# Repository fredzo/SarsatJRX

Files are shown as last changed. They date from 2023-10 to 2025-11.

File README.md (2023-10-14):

# Sarsat JRX
Cospas/Sarsat 406MHz beacon decoder based on an ESP32 module.
This project was inspired by the work of F4GMU and F1LVT.

Field use during a SATER exerciser with Ardrasec 31 :

Field use

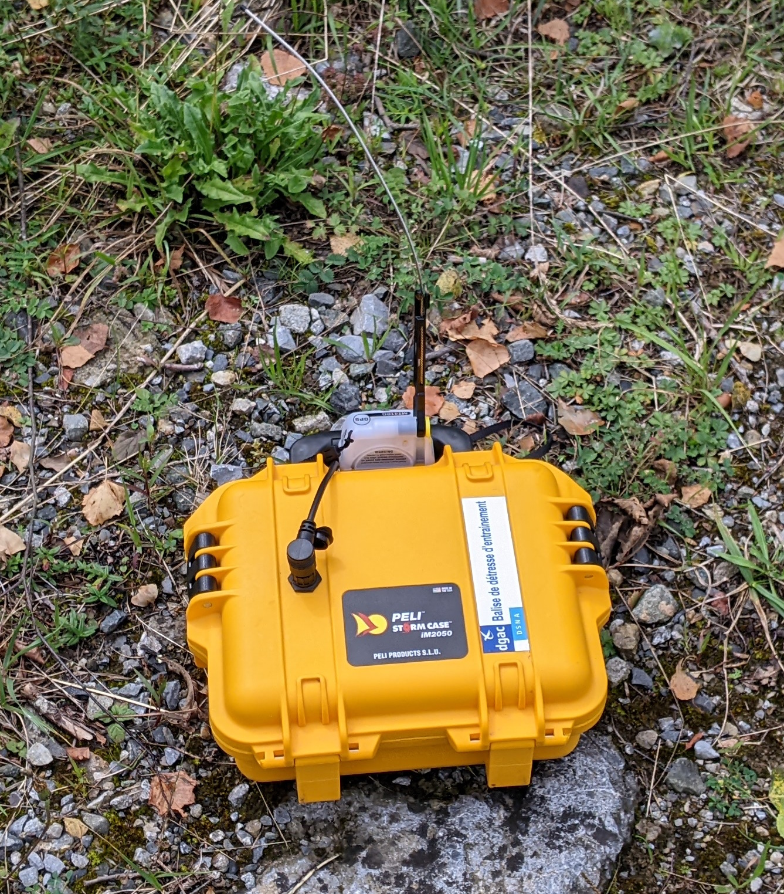
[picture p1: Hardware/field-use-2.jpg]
Field use


# Hardware
Input stage is based on F1LVT's "deriv-audio" board : http://www.f1lvt.com/files/346-DerivAudio-P3.90.pdf

Second stage is F1LVT's signal shaping stage from DECTRA decoder : http://www.f1lvt.com/files/333E-ConstructionDECTRA2274-P1-English.67.pdf

Audio signal can be provided by either the audio ouput of a receiver (in my case a FT3D portable) or from a NiceRF SA818-S UHF module.

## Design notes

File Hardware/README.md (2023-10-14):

# Hardware

The board used is an LilyGo LilyPi : https://opencircuit.fr/produit/lilygo-lily-pi-esp32-wifi-bluetooth-3.5-inch
Based on an ESP32-Wrover-E module from Espressif.

Input stage is based on F1LVT's "deriv-audio" board : http://www.f1lvt.com/files/346-DerivAudio-P3.90.pdf
Second stage is F1LVT's signal shaping stage from DECTRA decoder : http://www.f1lvt.com/files/333E-ConstructionDECTRA2274-P1-English.67.pdf

Audio signal can be provided by either the audio ouput of a receiver or from a NiceRF SA818-S UHF module.

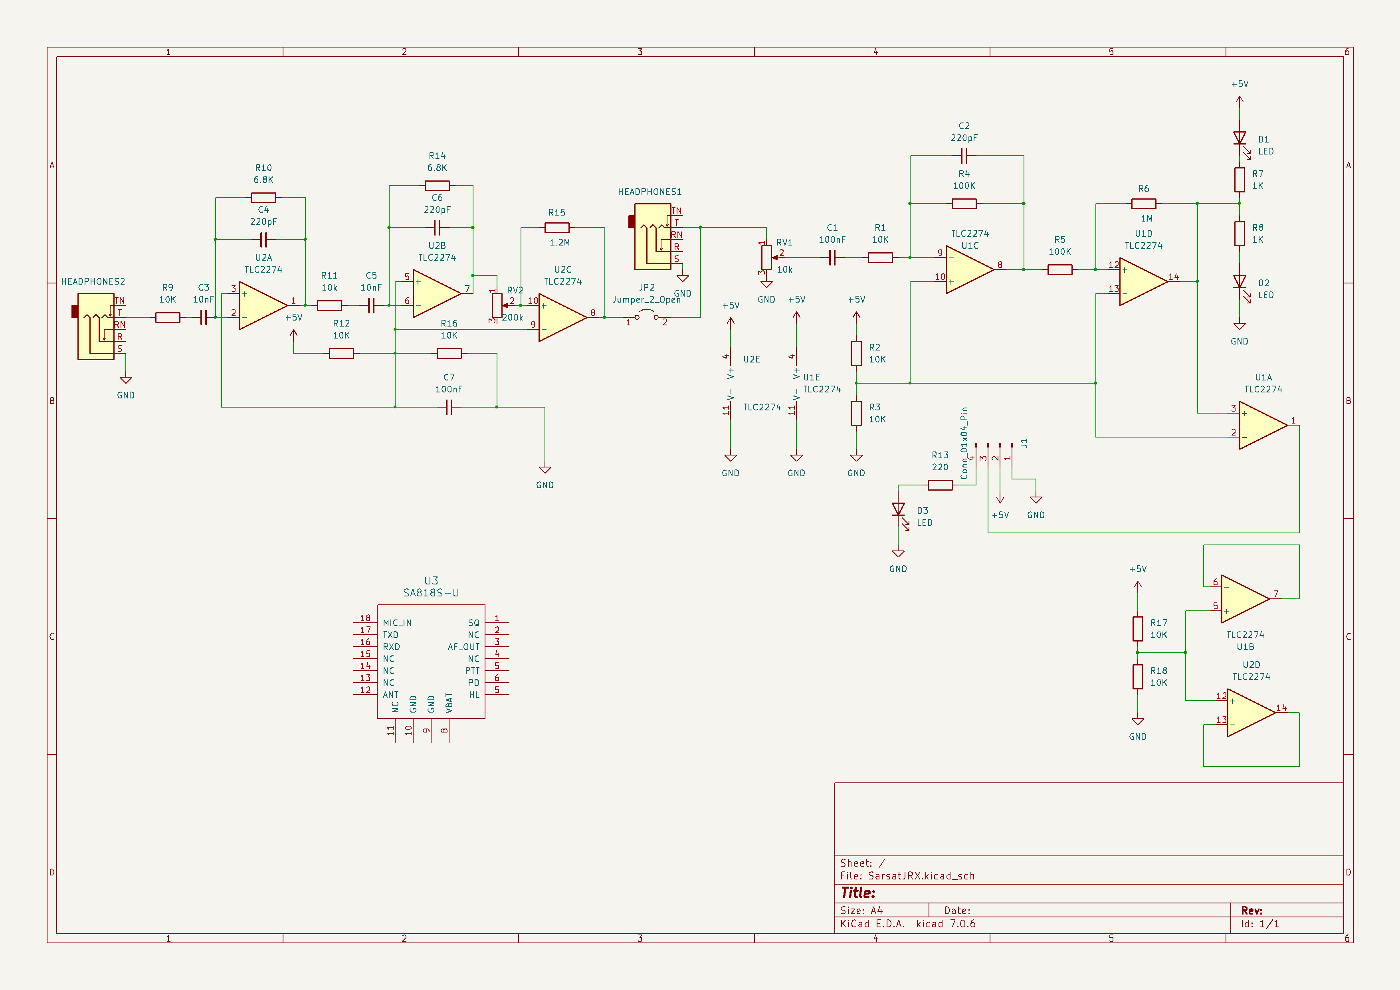
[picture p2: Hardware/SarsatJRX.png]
Schematic


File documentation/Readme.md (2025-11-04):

# **_SarsatJRX_** Beacon Decoder documentation
This is the documentation of F4JRX's SarsatJRX Beacon Decoder.

## Description
SarsatJRX is a COSBAS/SARSAT 406 MHz Beacon Decoder.

It's been developed by F4JRX, emergency radio operator from french civil security association [ADRASEC 31](https://adrasec31.canalblog.com/).
SarsatJRX is meant to be used on the ground to help locating emergency beacons from [COSPAS/SARSAT](https://www.cospas-sarsat.int/) system.

Once connected to an UHF FM receiver tuned to the beacon frequency, SarsatJRX will decode the 406 frames transmitted by the beacon and show its GPS coordinates.
Coordinates can sent to a phone for direction finding, either by scanning a QR Code on SarsatJRX's screen, or by connecting the [[dedicated app|SarsatJRX App]] to the decoder.

## Getting Started
### Hardware Setup
Check the [[Hardware Setup]] page for instructions on how to connect your SarsatJRX decoder to your receiver.
This page also describes different parts of you decoder.

### Configuration
The [Configuration] page will guide you through the basic configuration of the decoder.

### Main screen
The [Main Screen] page describes the information available on SarsatJRX's main screen.

### Connecting SarsatJRXApp
Once your SarsatJRX decoder is up and running, you may want ton connect it to SarsatJRXApp for easier communication with your phone.
Check the [[SarsatJRXApp]] connection page for instructions on how to connect the app to the decoder.

## Settings
There are various parameters that can be adjusted in SarsatJRX decoder.
Check the [[Settings]] page for more details.

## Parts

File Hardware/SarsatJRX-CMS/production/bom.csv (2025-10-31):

Designator | Footprint | Quantity | Value | LCSC Part #
BZ1 | MagneticBuzzer_PUI_AT-0927-TT-6-R-side-horn | 1 | Buzzer
C1, C10, C7, C8, C9 | 0603 | 5 | 100nF
C11, C13 | CP_EIA-3216-18_Kemet-A | 2 | 10uF
C12 | CP_Radial_D10.0mm_P5.00mm | 1 | 3300uF
C2, C4, C6 | 0603 | 3 | 220pF
C3, C5 | 0603 | 2 | 10nF
D1, D2, D3, D4 | LED_D5.0mm | 4 | LED
HEADPHONES1, HEADPHONES2 | PJ-307 | 2 | AudioJack3_SwitchTR
J3 | RPI_Hat_B+ | 1 | LilyPi GPIO Header
Q1 | SOT-23-3_L3.0-W1.7-P0.95-LS2.9-BR | 1 | S8050
R1, R11, R12, R16, R17, R18, R2, R24, R3, R9 | 0603 | 10 | 10K
R10, R14 | 0603 | 2 | 6.8K
R13, R19 | 0603 | 2 | 220
R15 | 0603 | 1 | 1.2M
R20, R21, R4, R5 | 0603 | 4 | 100K
R22, R7, R8 | 0603 | 3 | 1k
R23 | 0603 | 1 | 2k
R25 | 0603 | 1 | 51
R26 | 0603 | 1 | 0
R6 | 0603 | 1 | 1M
RV1 | Potentiometer_Bourns_3296W_Vertical | 1 | 10k
RV2 | Potentiometer_Bourns_3296W_Vertical | 1 | 200k
TP1, TP2, TP3, TP4, TP5, TP6, TP7, TP8 | TestPoint_Pad_D1.0mm | 8 | ~
U1, U2 | SOIC-14_3.9x8.7mm_P1.27mm | 2 | TLC2274

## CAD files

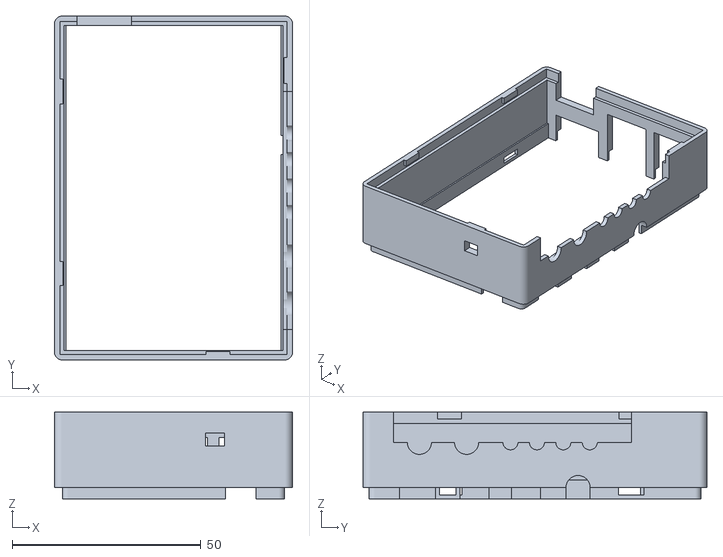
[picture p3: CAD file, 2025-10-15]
Hardware/Case/Extender.stl
63.0 x 91.0 x 23.0

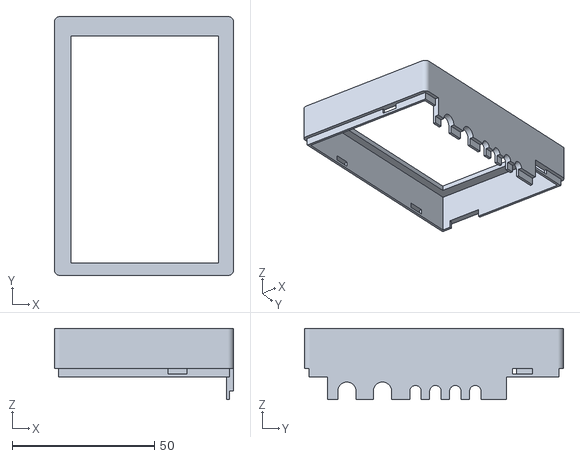
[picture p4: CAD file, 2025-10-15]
Hardware/Case/Top.stl
63.0 x 91.0 x 25.1

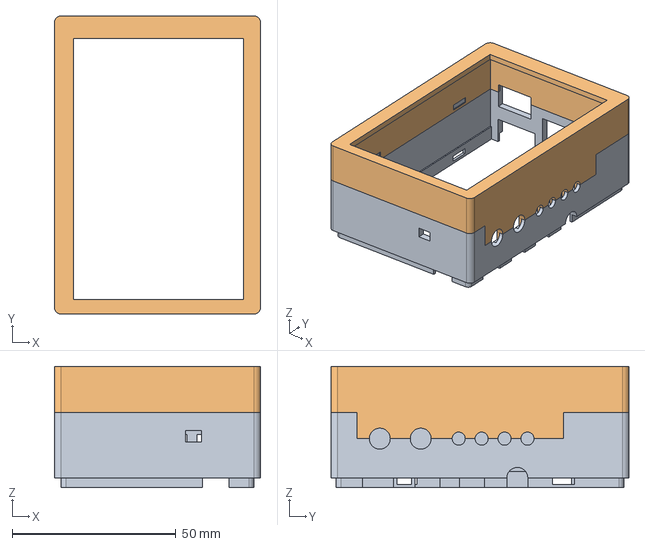
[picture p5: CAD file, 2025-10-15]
Hardware/Case/SarsatJRX Case Extender.FCStd
63.0 x 91.0 x 37.1 mm
Extender
Top

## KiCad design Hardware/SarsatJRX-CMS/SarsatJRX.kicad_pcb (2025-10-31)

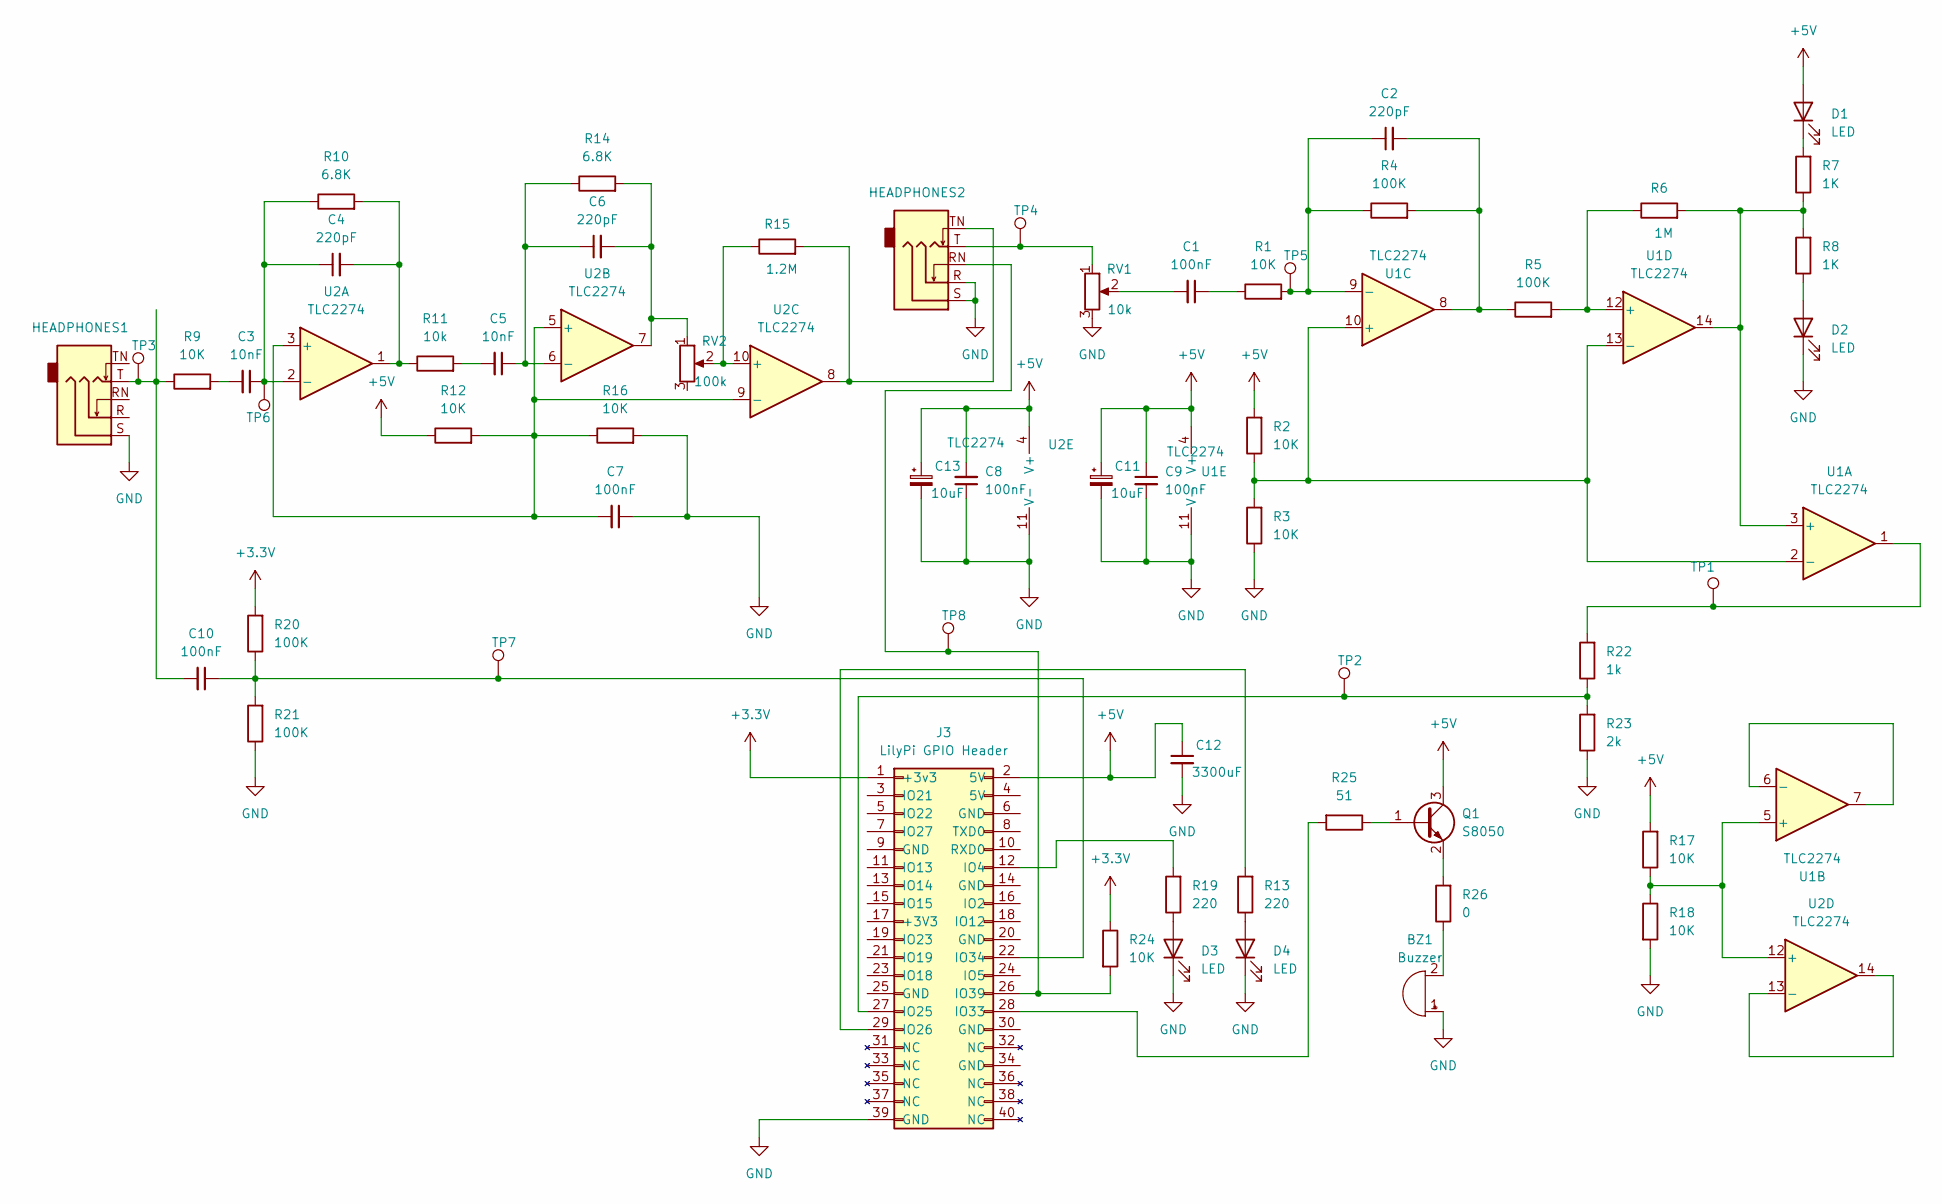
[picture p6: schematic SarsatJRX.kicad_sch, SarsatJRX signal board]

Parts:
BZ1: Buzzer; MagneticBuzzer_PUI_AT-0927-TT-6-R-side-horn
C1, C7, C8, C9, C10: 100nF; C_0603_1608Metric
C2, C4, C6: 220pF; C_0603_1608Metric
C3, C5: 10nF; C_0603_1608Metric
C11, C13: 10uF; CP_EIA-3216-18_Kemet-A
C12: 3300uF; CP_Radial_D8.0mm_P3.50mm
D1, D2, D3, D4: LED; LED_D5.0mm
HEADPHONES1, HEADPHONES2: AudioJack3_SwitchTR; PJ-307
J3: LilyPi GPIO Header; RPI_Hat_B+
Q1: S8050; SOT-23-3_L3.0-W1.7-P0.95-LS2.9-BR
R1, R2, R3, R9, R12, R16, R17, R18, R24: 10K; R_0603_1608Metric
R4, R5, R20, R21: 100K; R_0603_1608Metric
R6: 1M; R_0603_1608Metric
R7, R8: 1K; R_0603_1608Metric
R10, R14: 6.8K; R_0603_1608Metric
R11: 10k; R_0603_1608Metric
R13, R19: 220; R_0603_1608Metric
R15: 1.2M; R_0603_1608Metric
R22: 1k; R_0603_1608Metric
R23: 2k; R_0603_1608Metric
R25: 51; R_0603_1608Metric
R26: 0; R_0603_1608Metric
RV1: 10k; Potentiometer_Bourns_3296W_Vertical
RV2: 100k; Potentiometer_Bourns_3296W_Vertical
TP1, TP2, TP3, TP4, TP5, TP6, TP7, TP8: TestPoint_Pad_D1.0mm
U1, U2: TLC2274; SOIC-14_3.9x8.7mm_P1.27mm

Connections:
+3.3V: J3.1 (+3v3), R20.2, R24.1
+5V: C8.2, C9.1, C11.1, C12.1, C13.1, D1.2 (A), J3.2 (5V), Q1.3 (C), R2.2, R12.1, R17.2, U1.4 (V+), U2.4 (V+)
GND: BZ1.1 (+), C7.1, C8.1, C9.2, C11.2, C12.2, C13.2, D2.1 (K), D3.1 (K), D4.1 (K), HEADPHONES1.S, HEADPHONES2.R, HEADPHONES2.S, J3.39 (GND), R3.1, R16.2, R18.2, R21.1, R23.1, RV1.3, U1.11 (V-), U2.11 (V-)
unnamed: BZ1.2 (-), R26.1
unnamed: C1.1, R1.1
unnamed: C1.2, RV1.2
unnamed: C2.2, R4.2, R5.1, U1.8
unnamed: C3.2, R9.2
unnamed: C4.2, R10.2, R11.1, U2.1
unnamed: C5.2, R11.2
unnamed: C6.2, R14.2, RV2.1, U2.7
unnamed: C10.2, HEADPHONES1.T, R9.1, TP3.1
unnamed: D1.1 (K), R7.2
unnamed: D2.2 (A), R8.1
unnamed: D3.2 (A), R19.1
unnamed: D4.2 (A), R13.1
unnamed: HEADPHONES2.T, RV1.1, TP4.1
unnamed: HEADPHONES2.TN, R15.2, U2.8
unnamed: J3.12 (IO4), R19.2
unnamed: J3.27 (IO25), R22.1, R23.2, TP2.1
unnamed: J3.29 (IO26), R13.2
unnamed: J3.28 (IO33), R25.2
unnamed: C10.1, J3.22 (IO34), R20.1, R21.2, TP7.1
unnamed: HEADPHONES2.RN, J3.26 (IO39), R24.2, TP8.1
unnamed: Q1.1 (B), R25.1
unnamed: Q1.2 (E), R26.2
unnamed: R22.2, TP1.1, U1.1
unnamed: R6.2, R7.1, R8.2, U1.3 (+), U1.14
unnamed: R2.1, R3.2, U1.2 (-), U1.10 (+), U1.13 (-)
unnamed: R17.1, R18.1, U1.5 (+), U2.12 (+)
unnamed: U1.6 (-), U1.7
unnamed: C2.1, R1.2, R4.1, TP5.1, U1.9 (-)
unnamed: R5.2, R6.1, U1.12 (+)
unnamed: C7.2, R12.2, R16.1, U2.3 (+), U2.5 (+), U2.9 (-)
unnamed: C3.1, C4.1, R10.1, TP6.1, U2.2 (-)
unnamed: C5.1, C6.1, R14.1, U2.6 (-)
unnamed: R15.1, RV2.2, U2.10 (+)
unnamed: U2.13 (-), U2.14

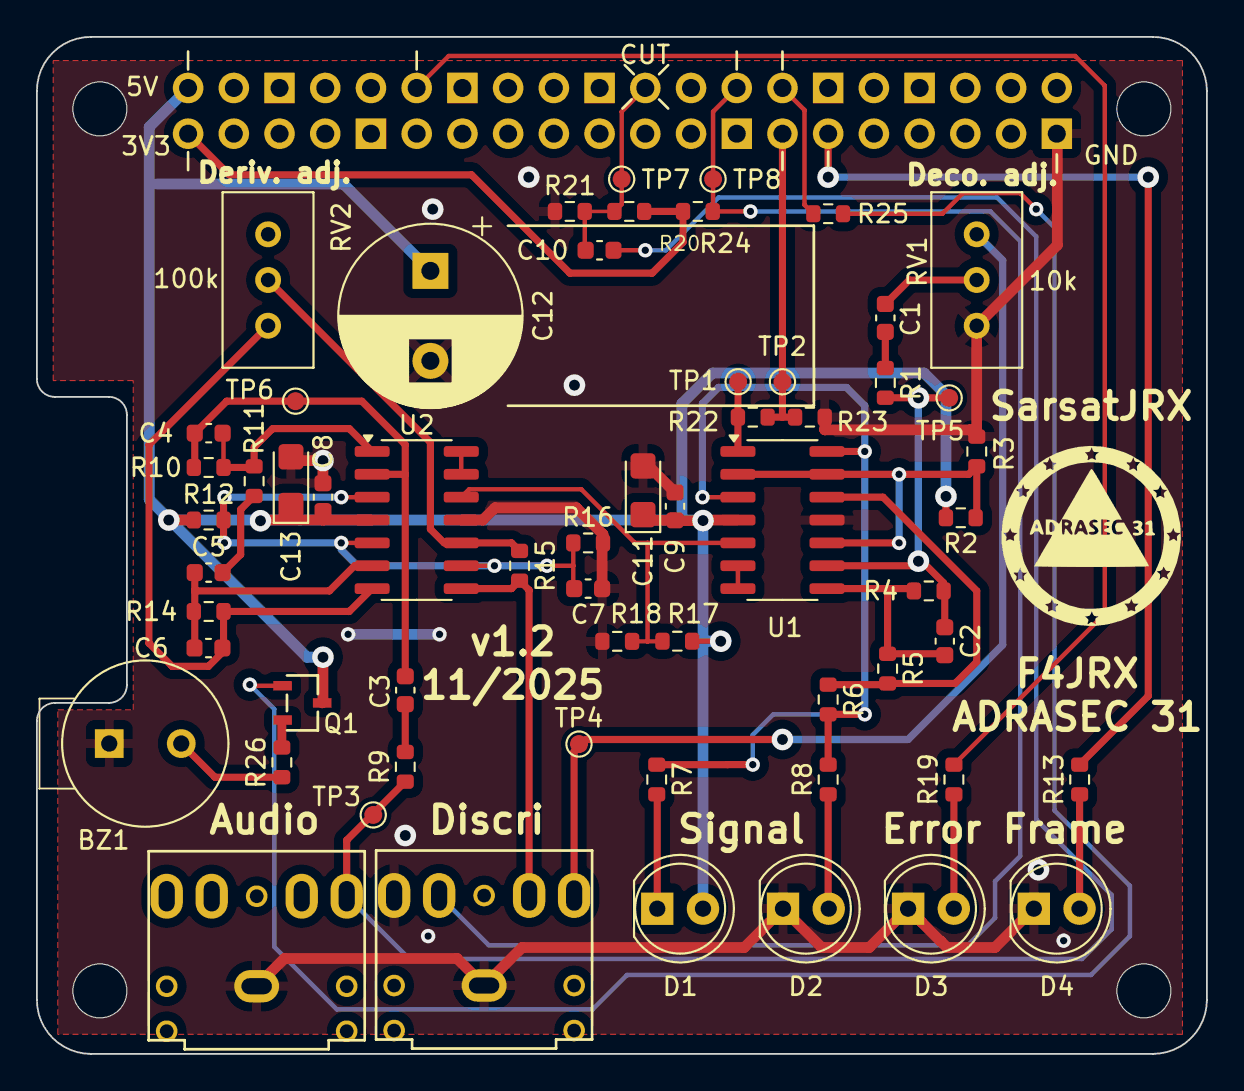
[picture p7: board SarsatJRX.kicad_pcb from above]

Board: 2 copper layers, 65.0 x 56.5 mm, 60 parts (0 on the bottom side), 38 nets.

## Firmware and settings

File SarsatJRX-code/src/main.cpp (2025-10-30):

/*******************************
   SarsatJRX
   406 Mhz Beacon Frame decoder
   Hardware : TTGO LilyPi
********************************/

#include <Arduino.h>

#include <SarsatJRXConf.h>
#include <Hardware.h>
#include <Location.h>
#include <Country.h>
#include <Beacon.h>
#include <Util.h>
#include <Samples.h>
#include <Decoder.h>
#include <WifiManager.h>
#include <BluetoothManager.h>

// Nedded if stack size of Arduino loop is too small
// SET_LOOP_TASK_STACK_SIZE(16*1024)

// Disri jack state
bool discriJackPlugged = false;

// Beacon list
Beacon* beacons[BEACON_LIST_MAX_SIZE];
int beaconsWriteIndex = -1;
int beaconsReadIndex = -1;
int beaconsSize = 0;
bool beaconsFull = false;

// Flag to update buzzer level in main loop core
bool updateBuzzerLevel = false;
uint8_t buzzerLevel = 0;

Hardware* hardware = nullptr; 
Display *display = nullptr;

typedef enum { BEACON_FILTER_NONE, BEACON_FILTER_INVALID, BEACON_FILTER_ORBITO } BeaconFilter;

BeaconFilter readBeacon()
{
  BeaconFilter filter = BEACON_FILTER_NONE;
#ifdef DEBUG_RAM
  Serial.println(freeRam());
#endif
  // Start by reading beacon
  Beacon* beacon;
  if(isFrameFromDisk())
  {
    beacon = new Beacon(getFrame(),getDiskFrameDate());
  }
  else
  {
    beacon = new Beacon(getFrame());
  }
  // See if we need to filter this beacon
  Settings* settings = hardware->getSettings();
  if((!beacon->isFrameValid())&&settings->getFilterInvalid())
  {
    filter = BEACON_FILTER_INVALID;
  }
  else if(beacon->isOrbito()&&settings->getFilterOrbito())
  {
    filter = BEACON_FILTER_ORBITO;
  }

  if(filter == BEACON_FILTER_NONE)
  { // No filtering => store the beacon in list
    if(beaconsFull)
    {
      beaconsWriteIndex++;
    }
    else
    { // Move to the end of the list
      beaconsWriteIndex = beaconsSize;
      if(beaconsSize < BEACON_LIST_MAX_SIZE)
      {
        beaconsSize++;
      }
      else
      {
        beaconsFull = true;
      }
    }
    if(beaconsWriteIndex >= BEACON_LIST_MAX_SIZE)
    { // Circle back to zero
      beaconsWriteIndex = 0;
    }
    // Delete previously stored beacon to prevent memory leak
    if(beacons[beaconsWriteIndex]) 
    {
        delete beacons[beaconsWriteIndex];
        beacons[beaconsWriteIndex] = nullptr;
    }
    // Add beacon to the list
    beacons[beaconsWriteIndex] = beacon;
    // Move to last received
    beaconsReadIndex = beaconsWriteIndex;
  }
  else
  { // Filter beacon => delete it to free memory
    delete beacon;
    beacon = nullptr;
  }

#ifdef DEBUG_RAM
  Serial.println(freeRam());
#endif
  return filter;
}

// Header LEDS
bool ledSig1State = false;
bool ledSig2State = false;
bool ledInFrameState = false;
bool ledFrameErrorState = false;
bool ledFrameReceivedState = false;

// Leds management (header + physical led)
#define LED_BLINK_TIME 2000 // 1 s
#define LED_BLINK_SHORT_TIME 100 // 100 ms
unsigned long ledsStartBlinkTime;
unsigned long ledSig1StartBlinkTime;
unsigned long ledSig2StartBlinkTime;
bool ledSig1On = false;
bool ledSig2On = false;
bool ledFrameErrorOn = false;
bool ledFrameReceivedOn = false;
bool lastInputState = false;
bool countDownModeOn = false;

void updateLeds()
{
  if((ledFrameReceivedOn || ledFrameErrorOn) && ((millis() - ledsStartBlinkTime)> (countDownModeOn ? LED_BLINK_SHORT_TIME : LED_BLINK_TIME)))
  { // Leds have been on long enough (long blink or short blink accordig to countdown mode beeing on or not)
    digitalWrite(NOTIFICATION_PIN, LOW); 
    digitalWrite(ERROR_PIN, LOW); 
    ledFrameReceivedOn = false;
    ledFrameErrorOn = false;
    countDownModeOn = false;
  }
}

// Store last displayed power value
unsigned long lastPowerDisplayTime = 0;

void updateLedHeader(bool force)
{ // Led header
  bool newInputState = getInputState();
  bool drawledSig1 = force;
  bool drawledSig2 = force;
  bool drawledInFrame = force;
  bool drawledFrameReceived = force;
  unsigned long now = millis();
  if(newInputState != lastInputState)
  { // Flip headerLedSig1 and headerLedSig2 according to decoder input stage state
    lastInputState = newInputState;
    ledSig1State = newInputState;
    ledSig2State = !newInputState;
    drawledSig1 = true;
    drawledSig2 = true;
    if(ledSig1State) ledSig1StartBlinkTime = now;
    if(ledSig2State) ledSig2StartBlinkTime = now;
  }
  else
  { // Check if we have to turn decoder input leds off
    if(ledSig1State && ((now - ledSig1StartBlinkTime) > LED_BLINK_TIME))
    {
      ledSig1State = false;
      drawledSig1 = true;
    }
    if(ledSig2State && ((now - ledSig2StartBlinkTime) > LED_BLINK_TIME))
    {
      ledSig2State = false;
      drawledSig2 = true;
    }
  }
  if((ledInFrameState != isFrameStarted()) || (ledFrameErrorState != ledFrameErrorOn))
  { // Check if frame started state changed
    ledInFrameState = isFrameStarted() || ledFrameErrorOn;
    ledFrameErrorState = ledFrameErrorOn;
    drawledInFrame = true;
  }
  if(ledFrameReceivedState != ledFrameReceivedOn)
  { // Check if frame received state changed
    ledFrameReceivedState = ledFrameReceivedOn;
    drawledFrameReceived = true;
  }
  if(drawledSig1) display->updateLedSig1(ledSig1State);
  if(drawledSig2) display->updateLedSig2(ledSig2State);
  if(drawledInFrame) display->updateLedInFrame(ledInFrameState,ledFrameErrorState);
  if(drawledFrameReceived) display->updateLedFrameReceived(ledFrameReceivedState);
}

void frameReceivedLedBlink()
{ // Switch led on and record time
  digitalWrite(NOTIFICATION_PIN, HIGH);
  ledFrameReceivedOn = true;
  ledsStartBlinkTime = millis();
  countDownModeOn = false;
  updateLedHeader(false);
}

void invalidFrameReceivedLedBlink()
{ // Switch led on and record time
  digitalWrite(ERROR_PIN, HIGH);
  ledFrameErrorOn = true;
  ledsStartBlinkTime = millis();
  countDownModeOn = false;
  updateLedHeader(false);
}

void updateHeader()
{ // Check for time update
  Rtc* rtc = hardware->getRtc();
  if(rtc->hasChanged())
  {
    display->updateTime();
  }
  // Check for power value update
  if(hardware->getPower()->hasChanged())
  {
    display->updatePower();
  }
  Audio* audio = hardware->getAudio();
  if(audio->discriHasChanged())
  {
    discriJackPlugged = audio->isDiscriInput();
    display->updateDiscri();
  }
  updateLedHeader(false);
}

void initHeader()
{
  // Time
  display->updateTime();
  // Draw leds
  updateLedHeader(true);
}

// Footer management
unsigned long lastFooterUpdateTime;
bool footerShowingFrameReceived = false;
bool footerShowingSpinner = false;
int spinnerPosition = 0;
#define FOOTER_FRAME_RECEIVED_TIME 2000
unsigned long lastAudioPowerUpdateTime;
#define FOOTER_POWER_UPDATE_TIME 100

void updateFooter(bool frameReceived)
{  
  unsigned long now = millis();
  if(footerShowingFrameReceived)
  {
    if((now - lastFooterUpdateTime) > FOOTER_FRAME_RECEIVED_TIME)
    {
      lastFooterUpdateTime = now;
      display->updateFrameReceived(false);
      footerShowingFrameReceived = false;
    }
  }
  else
  {
    if(frameReceived)
    {
      lastFooterUpdateTime = now;
      display->updateFrameReceived(true);
      footerShowingFrameReceived = true;
    }
  }
  // Audio
  if(!discriJackPlugged && (now - lastAudioPowerUpdateTime) > AUDIO_POWER_DISPLAY_PERIOD)
  { // Only update audio metter if dscri jack is not plugged
    lastAudioPowerUpdateTime = now;
    display->updateAudioPower();
  }
}

void updateDisplay()
{
#ifdef DEBUG_RAM
  Serial.println(freeRam());
#endif
  // Rotating index based on beacon list max size and position of last read frame
  int displayIndex = ((beaconsSize-1 + beaconsReadIndex - beaconsWriteIndex) % BEACON_LIST_MAX_SIZE)+1;
  display->updateBeacon(beacons[beaconsReadIndex],displayIndex,beaconsSize);
#ifdef DEBUG_RAM
  Serial.println(freeRam());
#endif

}

void readNextSampleFrame()
{ // Read the frame content
  readNextSample(getFrame());
  // Tell the state machine that we have a complete frame
  setFrameComplete(true);
}

bool readBeaconFromFile(const char* fileName)
{ // Read the frame content
  if(hardware->getFilesystems()->loadBeacon(fileName,getFrame()))
  { // Tell the state machine that we have a complete frame
    setFrameComplete(true);
    setFrameFromDisk(parseBeaconFileName(fileName));
    return true;
  }
  else
  {
    return false;
  }
}

void stopCountdownAutoReload()
{ // Skip directly to -1 to prevent auto-reload
  Rtc::getRtc()->setCountDown(-1);
}

void setup()
{ // First show boot screen
  digitalWrite(LILYPI_TFT_BL,0); // Force BL off for now
  hardware = Hardware::getHardware();
  hardware->bootScreen();
  
  // Init beacon list
  for(int i=0; i<BEACON_LIST_MAX_SIZE; i++) beacons[i] = nullptr;

  // For heap corruption debugging
  //heap_caps_print_heap_info(MALLOC_CAP_DEFAULT);

  pinMode(RECEIVER_PIN, INPUT);          // Detection stage input
  pinMode(NOTIFICATION_PIN, OUTPUT);     // Notification led output
  pinMode(ERROR_PIN, OUTPUT);            // Error led output
  pinMode(BUZZER_PIN, OUTPUT);           // Buzzer output


  
  Serial.begin(115200);
  attachInterrupt(digitalPinToInterrupt(RECEIVER_PIN), analyze, CHANGE);  // interruption sur Rise et Fall

  hardware->init();
  display = hardware->getDisplay();

#ifdef WIFI
  if(hardware->getSettings()->getWifiState())
  {
    wifiManagerStart();
    display->updateWifi();
  }
#endif

  display->updateSdCard();
  display->updateDiscri();

  Settings* settings = hardware->getSettings();

  display->setReverse(settings->getDisplayReverse());

  // UI is now ready : start display task
  display->startDisplayTask();

  // Init buzzer level
  hardware->getSoundManager()->setVolume(settings->getBuzzerLevel());

  //readNextSampleFrame();
#ifdef SERIAL_OUT 
  Serial.println("### Boot complete !");
#endif
}

void previousFrame()
{
    beaconsReadIndex--;
    if(beaconsReadIndex<0)
    {
      beaconsReadIndex = beaconsSize-1;
    }
    updateDisplay();
}

void nextFrame()
{
    beaconsReadIndex++;
    if(beaconsReadIndex>=beaconsSize)
    {
      beaconsReadIndex = 0;
    }
    updateDisplay();
}

void blinkNotifLed()
{
  if(!ledFrameReceivedOn)
  { // Blink leds if not already showing received frame
    digitalWrite(NOTIFICATION_PIN, HIGH);
    ledFrameReceivedOn = true;
    ledsStartBlinkTime = millis();
    countDownModeOn = true;
  }
}

void blinkErrorLed()
{
  if(!ledFrameReceivedOn)
  { // Blink leds if not already showing received frame
    digitalWrite(ERROR_PIN, HIGH);
    ledFrameErrorOn = true;
    ledsStartBlinkTime = millis();
    countDownModeOn = true;
  }
}

void loop()
{
  // Audio task
  hardware->getAudio()->handleTask();
  // Power task
  hardware->getPower()->handleTask();
  // Get rtc
  Rtc* rtc = hardware->getRtc();
  Settings* settings = hardware->getSettings();
  // If frameParseState > 0, we are reading an frame, if more than 500ms elapsed (a frame should be 144x2.5ms = 360 ms max)
  bool frameTimeout = (isFrameStarted() && ((millis()-getFrameStartTime()) > 500 ));
  if (isFrameComplete() || frameTimeout)
  { // Get frame content
    volatile byte* frame = getFrame();
    // Debug purpose 
 #ifdef SERIAL_OUT 
   if(frameTimeout)
    {
      Serial.println("Frame timeout !");
    }
    for ( byte i = 0; i < Beacon::SIZE; i++) // RAW data
    {
      if (frame[i] < 16)
      Serial.print('0');
      Serial.print (frame[i], HEX);
      Serial.print(" ");
    }
    Serial.println("");
  #endif
  #ifdef DEBUG_DECODE
    int* events = getEvents();
    int eventCount = getEventCount();
    for ( int i = 0; i < eventCount; i++)
    {
      Serial.println(events[i],DEC);
    }
    Serial.println("");
    bool* bits = getBits();
    int bitCount = getBitCount();
    for (int i = 0; i < bitCount; i++)
    {
      Serial.print(bits[i],DEC);
    }
    Serial.println("");
  #endif    

    if(((frame[1] == 0xFE) && (frame[2] == 0xD0)) || ((frame[1] == 0xFE) && (frame[2] == 0x2F)))// 0XFE/0x2F for normal mode, 0xFE/0xD0  for autotest
    { // Blink blue led
      frameReceivedLedBlink();
      // Then read beacon and update beacon display
      BeaconFilter filter = readBeacon();
      Beacon* currentFrame = nullptr;
      if(filter == BEACON_FILTER_NONE)
      { // Start countdown for next frame only if not filtered
        rtc->startCountDown();            
        // Play sound and update error led and display
        currentFrame = beacons[beaconsReadIndex];
        bool error = !(currentFrame->isFrameValid());
        if(error)
        { // Error led
          invalidFrameReceivedLedBlink();
          Serial.println("Frame error !");
        }
        if(settings->getFrameSound())
        {
          hardware->getSoundManager()->playFrameSound(error);
        }
        updateDisplay();
        if(!isFrameFromDisk())
        { // Finally save beacon to sd card
          bool success = hardware->getFilesystems()->saveBeacon(currentFrame);
          if(!success)
          { // Update SD Card indicator
            display->updateSdCard();
          }
        }
        // Unfiltered frame
        wifiManagerSendFrameEvent(currentFrame,beaconsReadIndex,true,false,error);
      }
      else
      { // Frame has been filterd
        if(filter == BEACON_FILTER_INVALID)
        { // Restert countdown on invalid frames if we were close to 0
          int currentCountDown = rtc->getCountDown();
          if(abs(currentCountDown)<=1)
          {
            rtc->startCountDown();
          }
          if(settings->getFrameSound()) hardware->getSoundManager()->playFrameSound(true);
          // Filtered error frame
          wifiManagerSendFrameEvent(currentFrame,beaconsReadIndex,true,true,true);
        }
        else
        {
          if(settings->getFrameSound()) hardware->getSoundManager()->playFilteredFrameSound();
          // Filtered orbito frame
          wifiManagerSendFrameEvent(currentFrame,beaconsReadIndex,true,true,false);
        }
        // Blink red led for filtered frames (valid or invalid)
        invalidFrameReceivedLedBlink();
      }
#ifdef WIFI
#endif    
    }
    else
    { // Frame preamble detected, but wrong start bytes
      // Restert countdown on invalid frames if we were close to 0
      int currentCountDown = rtc->getCountDown();
      if(abs(currentCountDown)<=1)
      {
        rtc->startCountDown();
      }
      // Error led
      invalidFrameReceivedLedBlink();
      Serial.println("Invalid frame !");
      if(settings->getFrameSound())
      {
        hardware->getSoundManager()->playInvalidFrameSound();
      }
#ifdef WIFI
      wifiManagerSendFrameEvent(nullptr,-1,false,true,true);
#endif    
    }
    // Reset frame decoding
    updateFooter(true);
    resetFrameReading();
  }
  else
  {
    updateFooter(false);
  }
  updateLeds();
  updateHeader();
  if(rtc->countDownHasChanged())
  {
    display->updateTicker();
    if(settings->getCountDownSound())
    { // Play countdown beeps
      if(rtc->isAlmostLastCount())
      {
        hardware->getSoundManager()->playCountDownLowSound();
      }
      else if (rtc->isLastCount())
      {
        hardware->getSoundManager()->playCountDownHighSound();
      }
    }
    if(settings->getCountDownLeds())
    {
      if(rtc->isAlmostLastCount())
      { // Blue led 4 times
        blinkNotifLed();
      }
      else if (rtc->isLastCount())
      { // Red led once
        blinkErrorLed();
      }
    }
#ifdef WIFI
    if(wifiManagerClientCount() > 0)
    {
      wifiManagerSendTickerEvent(rtc->getCountDown(),hardware->getFilesystems()->isSdFilesystemMounted(),hardware->getAudio()->isDiscriInput(),hardware->getPower()->getBatteryPercentage(),rtc->getTimeString());
    }
#endif    
    if((rtc->getCountDown()==0) && settings->getReloadCountDown())
    {
      rtc->startCountDown();
    }
  }

    // Web and wifi
#ifdef WIFI
    if(wifiManagerHandleClient())
    {
      display->updateWifi();
    }
#endif
#ifdef BLUETOOTH
    if(bluetoothManagerHandleClient())
    {
      //TODO display->updateBluetooth();
    }
#endif
  // Save settings if needed
  hardware->getSettings()->handleTask();

  if(updateBuzzerLevel)
  {
    hardware->getSoundManager()->setVolume(buzzerLevel);
    SoundManager::getSoundManager()->playTouchSound();
    updateBuzzerLevel = false;
  }
  //delay(5);
}

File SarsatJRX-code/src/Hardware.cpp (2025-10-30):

#include <Hardware.h>
#include <Power.h>
#include <SarsatJRXConf.h>

Hardware *Hardware::hardware = nullptr;

void Hardware::bootScreen()
{
    display = new Display();
    display->bootScreen();
}

void Hardware::init()
{
    i2c = new I2CBus(Wire,I2C_SDA_PIN,I2C_SCL_PIN);
    power = Power::getPower();
    power->powerInit();
    rtc = Rtc::getRtc();
    rtc->rtcInit(i2c);
    filesystems = Filesystems::getFilesystems();
    filesystems->init();
    settings = Settings::getSettings();
    settings->init();
    if(!display) bootScreen();
    display->setup(i2c);
    audio = Audio::getAudio();
    audio->audioInit();
    soundManager = SoundManager::getSoundManager();
    soundManager->init();
}

Display* Hardware::getDisplay()
{
    return display;
}

Rtc* Hardware::getRtc()
{
    return rtc;
}

Settings* Hardware::getSettings()
{
    return settings;
}

Audio* Hardware::getAudio()
{
    return audio;
}

Power* Hardware::getPower()
{
    return power;
}

Filesystems* Hardware::getFilesystems()
{
   return filesystems;
}

SoundManager* Hardware::getSoundManager()
{
   return soundManager;
}

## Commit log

2023-07-31 Renamed code floder. Added test frames. Some comments and variables renaming. First step to Location class
2023-07-31 Fixed frame display
2023-08-01 More code cleanup and refactoring. Added QR code generation.
    [countries.csv]
2023-08-02 Memory optimization. Fixed button display.
    [Display.cpp, Display.h, main.cpp]
2023-08-03 Fixed some protocol desciptions. Added ELT(DT) and RTS Location parsing.
    [frame-bits.xlsx]
2023-08-03 Added button status. Fixed beacon URL.
    [Display.cpp, Display.h, main.cpp]
2023-08-04 Big refactoring for buttons
2023-08-04 Fist step to navigation buttons
2023-08-04 Added frames navigation. Made buttons finger friendly.
2023-08-04 Fixed beacon rotating list handling.
    [main.cpp]
2023-08-04 Created a function to extract bits from the beacon frame.
2023-08-11 Rework of decoding algorithm. Added notification led. Added debug ram and debug decode directives.
    [main.cpp]
2023-08-11 Fixed frame start detection
    [main.cpp]
2023-08-11 Fixed start frame size
    [main.cpp]
2023-08-11 Fixed frame end detection.
    [main.cpp]
2023-08-13 Added excel tools for frame decoding
    [decoder.xlsx, frame-bits.xlsx]
2023-08-14 First step to led header.
2023-08-14 Added led display
2023-08-14 Added header leds
2023-08-19 Fixed QR code display after refactoring
    [Display.cpp]
2023-08-19 Fixed header leds display
    [Display.h, main.cpp]
2023-08-20 First step to BCH fix
    [Beacon.cpp]
2023-08-26 Fixed BCH calculation and check
    [Beacon.cpp, main.cpp]
2023-08-26 Fixed BCH OK and green led colors
    [Display.cpp, Display.h, main.cpp]
2023-08-26 Fixed led header flickering
    [main.cpp]
2023-08-27 Finally fixed decoder !
    [main.cpp]
2023-08-28 First step to Arduino GFX display driver.
2023-08-28 Finished migration to Arduino GFX + some display refresh enhancements.
2023-08-28 Moved to XPT2046 touch driver (+ added touch calibration mode).
2023-08-29 Added additionnal data, serial number and loacting devices parsing and display.
2023-08-29 LVGL will have to wait for ESP32 board !...
2023-08-31 First step to ESP32 platform
2023-09-01 Added RTC driver
2023-09-01 Try and solve I2c communication problem with touch controller
    [Display.cpp, RTC.cpp, main.cpp]
2023-09-02 Keep on moving to ESP32
2023-09-02 Esp32 with Arduino GFX Driver => color problem...
    [Display.cpp, Display.h, Hardware.cpp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]
2023-09-03 Finally fixed TFT_eSPI with official latest version
    [Display.cpp]
2023-09-04 Fixed display and touch management.
    [Display.cpp, Display.h, Power.cpp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]
2023-09-06 Finally got RTC interrupt to work !
2023-09-09 Display code cleanup, fix led positionning
    [Display.cpp, Display.h, Hardware.cpp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]
2023-09-09 Fixed some styles, added beacon receive date/time
    [Beacon.cpp, Ui.cpp, main.cpp]
2023-09-10 Fixed bg color for better readability
    [Ui.cpp, UiBeacon.cpp]
2023-09-11 Fixed c_str() dangling pointers
    [UiBeacon.cpp]
2023-09-11 Fixed led blinking.
2023-09-13 Fixed RSSI change threshold
    [WifiManager.cpp]
2023-09-15 Fixed logo + SD Card pins
    [SarsatJRXConf.h, Ui.cpp]
2023-09-16 Fixed header positions, added beacon save to SD card.
    [Filesystems.cpp, SarsatJRXConf.h, Ui.cpp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]
2023-09-16 Added card remove detection on file write error.
    [Filesystems.cpp, main.cpp]
2023-09-16 Fixed power display
2023-09-21 Fixed wifi off label
    [WifiManager.cpp]
2023-09-25 Added mount/unmoint callbacks on sd card toggle
2023-09-27 Changed beacon buttons to iindividual buttons + added a create image button method
2023-09-27 First step to beacon load + fixed beacon header height
    [Filesystems.cpp, UiBeacon.cpp, main.cpp]
2023-09-27 Event handling traces
2023-09-28 FIrst step to radio module => added DRA818 lib as a submodule to fork the original lib which doesn't support EPS32
    [RTC.cpp, SarsatJRXConf.h]
2023-09-28 Moved all PIN declarations to SarsatJRX conf file + first step to DRA818 lib use.
2023-10-03 Removed old trace. Fixed dra lib.
2023-10-03 First step to power metter.
2023-10-04 Switched to async mode for dra module
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2023-10-06 Fixed scan button behaviour
    [Ui.cpp, WifiManager.cpp, main.cpp]
2023-10-11 Added radio buttons and keyboard
2023-10-12 Finaly found a working keyboard implementation.... Lvgl v8.3.9 (same with 8.3.10) as a bug that makes the whole keyboard re-render on each keystroke. A working solution has been found but needs to re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
    [Ui.cpp]
2023-10-12 Fixed freq textarea + added content control
    [Ui.cpp]
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2023-10-12 Added filter toggles. Fixed beacon count when deleting beacons.
2023-10-12 Added filter and volume settings.
2023-10-12 Fixed filter toggle init
2023-10-13 Fixed frequ list order and size
    [UiSettingsRadio.cpp]
2023-10-15 Fixed frequency item formatting. Fixed frequency increment.
    [UiSettingsRadio.cpp]
2023-10-15 Fixed freq list display
    [UiSettingsRadio.cpp]
2024-04-10 Disabled psram due to eratic memory crashes. Fixed ArduinoJSon version for AutoConnect Moved to SA818S radion and added decoder pin. Fixed beacon decoder URL to match new version. Added volume contro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
    [UiBeacon.cpp, UiSettingsRadio.cpp, main.cpp]
2024-04-13 Fixed radioVolume ui update
    [Ui.cpp, UiSettings.h, UiSettingsAudio.cpp]
2024-04-13 Fixed radio power UI
    [SarsatJRXConf.h, Ui.cpp, UiSettingsAudio.cpp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]
2024-04-13 Reduced beacon list size to reduce memory issues Fixed radio calls (only rssi and scan are async + call filters after group command to set them back
    [main.cpp]
2024-04-13 Fixed power meter range
    [SarsatJRXConf.h]
2025-05-04 Added Kicad files for TH and CMS hardware versions.
    [SarsatJRX.kicad_pcb, SarsatJRX.kicad_sch, bom.csv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]
2025-05-08 Removed radio stuff. First step to audio input measurement. First step to new PCB.
2025-05-23 Added schematics.
    [SarsatJRX.kicad_sch]
2025-05-31 First step to case extender.
    [SarsatJRX Case Extender.FCStd]
2025-05-31 Added top cuttings
    [SarsatJRX Case Extender.FCStd]
2025-05-31 Added jack and led cuts
    [SarsatJRX Case Extender.FCStd]
2025-06-01 Fist step tp top
    [SarsatJRX Case Extender.FCStd]
2025-06-01 Next step to top
    [SarsatJRX Case Extender.FCStd]
2025-06-01 FInished top front holes !
    [SarsatJRX Case Extender.FCStd]
2025-06-01 Added top filet.
    [SarsatJRX Case Extender.FCStd]
2025-06-02 Added anchors to extender
    [SarsatJRX Case Extender.FCStd]
2025-06-02 Finihed top anchors
    [SarsatJRX Case Extender.FCStd]
2025-06-02 Fixed switch cutout
    [SarsatJRX Case Extender.FCStd]
2025-06-02 Fixed transformation names.
    [SarsatJRX Case Extender.FCStd]
2025-06-02 Added mesh versions
    [SarsatJRX Case Extender.FCStd]
2025-06-02 Added stl files
    [Extender.stl, Top.stl]
2025-06-03 Added printing holders
    [SarsatJRX Case Extender.FCStd]
2025-07-26 Rmoved printing holders
    [SarsatJRX Case Extender.FCStd]
2025-07-26 Enlarged extender
    [SarsatJRX Case Extender.FCStd]
2025-07-26 Enlarged top
    [SarsatJRX Case Extender.FCStd]
2025-07-27 Firs step to realingning holes
    [SarsatJRX Case Extender.FCStd]
2025-07-27 Fixed realigning holes
    [SarsatJRX Case Extender.FCStd]
2025-07-27 Fixed switch hole
    [SarsatJRX Case Extender.FCStd]
2025-07-27 Fixed screen hole size
    [SarsatJRX Case Extender.FCStd]
2025-07-27 Fixed hole shape
    [SarsatJRX Case Extender.FCStd]
2025-07-27 New export
    [Extender.stl, Top.stl]
2025-07-29 First step to new inputs and ouptus (error led, buzzer, disci jack, charge etc.).
    [Audio.cpp, Hardware.cpp, Power.cpp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]
2025-07-29 Moved power functions in a dedicated class
2025-07-30 Fixed charging detection logic
    [Hardware.cpp, Power.cpp, main.cpp]
2025-07-31 Fixed power module (flickering led state detection + optimization of adc sampling logic). Some ui refactoring.
    [Power.cpp, Power.h, SarsatJRXConf.h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]
2025-07-31 Moved lvgl handle_timer to a dedicated task. Increased stack for Arduino loop. Fixed pin assignation. Keep settings screen when receiving a frame.
    [Display.cpp, Display.h, Power.cpp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]
2025-08-01 Added in frame led error handling.
    [Ui.cpp, main.cpp]
2025-08-01 Fixed ui update logic.
    [Display.cpp, Filesystems.cpp]
2025-08-01 Fixed error led logic.
    [main.cpp]
2025-08-02 Added small font (12px). Added battery percentage calculation. Added new settings (not used yet). Added battery indicator in header. Added battery percentage in system screen.
2025-08-02 Added rolling average for power measurment. Added parametrable min and max values for battery voltage. Fixed battery icon width.
    [Power.cpp, Power.h, Ui.cpp]
2025-08-02 Fixed battery indicator.
2025-08-02 Added raw power value.
2025-08-02 First step to adding buzzer.
    [Hardware.cpp]
2025-08-03 Changed pwm channel for sound manager. Moved all sprintf to snprintf.
2025-08-03 Fixed footer display logic
    [Display.h]
2025-08-03 Fixed style leak on footer.
    [Ui.cpp]
2025-08-03 Fixed delete beacon logic. Added sound on frame receive.
    [main.cpp]
2025-08-04 Fixed power charge detection timing.
    [Power.cpp]
2025-08-04 Chaged audio adc to IO39 and disci jack detection input to IO34 (since IO39 does not support internal pull-up).
2025-08-04 Fixed power state calculation timings.
    [Power.cpp]
2025-08-04 Restored pin assignement since IO34 needs external pull-up too anyway...
2025-08-04 Added ticker and frame annoucement support.
2025-08-04 Fixed footer style for frame notif.
    [Ui.cpp]
2025-08-04 Fixed logo positionning with discri icon.
    [Ui.cpp]
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2025-08-06 Added allow frame simulation settings. Fixed screen saver dialog. Fixed ':' formatting. Fixed buzzer level spinbox
    [Settings.cpp, Ui.cpp, UiBeacon.cpp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]
2025-08-06 Fixed screen saver management. Added screen on when receiving frame and going to battery unplugged mode.
    [Display.cpp, Power.cpp, Power.h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]
2025-08-06 Fixed screen saver logic.
    [Ui.cpp]
2025-08-06 Added settings to show battery warn message. Added Turn Off button on display settings. Fixed buzzer level spinbox font.
    [Settings.cpp, Ui.cpp, UiSettings.h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]
2025-08-06 Fixed battery off detection and charge state changed status.
    [Power.cpp, Power.h]
2025-08-06 Tried to solve full vs on battery iatus.
2025-08-06 Moved led blink to dedicated methods.
2025-08-06 Added charging led indicators.
2025-08-06 Fixed full notif led.
    [Ui.cpp]
2025-08-08 Only show battery dialog once.
2025-08-11 First step to v1.1 of the board : - Added buzzer on IO33 - Mouved led err to IO04 - Added voltage adaptation (5v->3.3v) on Receiver pin (IO25) - Added discri jack insertion detection on IO39 - Added 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
    [SarsatJRX.kicad_pcb, SarsatJRX.kicad_sch]
2025-08-11 Added test points.
    [SarsatJRX.kicad_pcb, SarsatJRX.kicad_sch]
2025-08-11 Removed solder mask from power vias on U1 and U2 to create test points.
    [SarsatJRX.kicad_pcb]
2025-08-11 Fixed snprintf calls when used buffer is not locally declared.
    [SarsatJRXConf.h, UiBeacon.cpp]
2025-08-11 Fixed some silkscreen
    [SarsatJRX.kicad_pcb]
2025-08-11 Fixed more silk screen. Added 2 test points.
    [SarsatJRX.kicad_pcb, SarsatJRX.kicad_sch]
2025-08-11 Fixed screen saver by blacking the display. Added screen on on usb power deconnection.
    [Display.cpp, Display.h, Ui.cpp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]
2025-08-11 Prepare for production.
    [SarsatJRX.kicad_pcb]
2025-08-11 Hardware v1.1 production files.
    [bom.csv, designators.csv, positions.csv]
2025-08-11 Fixed screen on logic.
    [Display.cpp]
2025-08-14 Added support for Orbitography Protocol frames with non BCH2.
2025-08-27 Addded bottom insertion fillet on extender
    [SarsatJRX Case Extender.FCStd]
2025-08-27 Fixed rear side opening positions (USB/Relay).
    [SarsatJRX Case Extender.FCStd]
2025-08-27 Fixed barrel jack position
    [SarsatJRX Case Extender.FCStd]
2025-08-27 Fixed top heigth
    [SarsatJRX Case Extender.FCStd]
2025-08-27 Added buzzer hole.
    [SarsatJRX Case Extender.FCStd]
2025-09-01 Fixed beacon screen after simu or sd read when in settings.
    [Ui.cpp]
2025-09-03 Added set system time at RTC startup to fix file dates on sd card.
    [RTC.cpp]
2025-09-04 Added red led + sound + countdown restart on invalid frame reception. Fixed reload countdown time. Removed use of RTC int timer (not working, probably hardware problem) and replaced with ESP32 hardwa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
    [RTC.cpp, Ui.cpp, main.cpp]
2025-09-05 Fixed invalid frame sound init
2025-09-05 Moved frame countdown duration to settings
2025-09-05 Fixed new symbols. Moved settings tab header to icons.
    [Ui.cpp]
2025-09-05 Fixed sd card access speed.
    [Filesystems.cpp]
2025-09-05 Fixed invalid frame notification.
    [main.cpp]
2025-09-06 Added new radio icon for frame settings. Cleaned-up audio settings tab. Added filter settings.
2025-09-07 Fixed battery detection.
2025-09-08 Added beacon filtering implementation.
2025-09-08 Fixed frame filter logic and sound.
    [main.cpp]
2025-09-09 Fixed frame filtering logic.
    [main.cpp]
2025-09-10 Only restart countdown on non filtered frames, or invalid frames, but close to countdown end.
2025-09-10 Prevent auto-reload countdown when overlapping.
    [RTC.cpp]
2025-09-10 Fixed main tab icons.
    [UiBeacon.cpp]
2025-09-10 Fixed QR display when location is not available.
    [UiBeacon.cpp]
2025-09-11 Moved back charge sate detection to mean power value rather than raw.
2025-09-11 Renamed buzzer hole sketch.
    [SarsatJRX Case Extender.FCStd]
2025-09-11 Fixed buzzer hole position
    [SarsatJRX Case Extender.FCStd]
2025-09-11 Fixed DC jack position.
    [SarsatJRX Case Extender.FCStd]
2025-09-11 Fixed bottom insertion fillet.
    [SarsatJRX Case Extender.FCStd]
2025-09-11 Fixed case
    [Extender.stl, Top.stl]
2025-09-11 Fixed Settings save management. Fixed wifi manager. Added wifi logo anim when not connected.
    [Settings.cpp, Ui.cpp, WifiManager.cpp]
2025-09-11 Fixed wifi blik anim.
    [Ui.cpp]
2025-09-12 Fixed NTP sync when current RTC year is > 2016.
    [RTC.cpp]
2025-09-12 Fixed NTP time sync.
    [RTC.cpp]
2025-09-14 Added timeZone to settings. Fixed NTP sync.
    [RTC.cpp, SarsatJRXConf.h, Settings.cpp]
2025-09-15 Added handling of conrner cases (empty frame etc.) in beacon parsing.
2025-09-15 Added emty frame to beacon screen.
2025-09-16 Added mDNS to resolve sarsatjrx.local
    [WifiManager.cpp]
2025-09-17 Failed attempt to add bluetooth: we don't have enough memory for both bluetooth and wifi, even if not activated. Let's stick with wifi.
    [BluetoothManager.cpp, SarsatJRXConf.h, Settings.cpp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]
2025-09-17 Update ntp state on ntp sync event. Fixed battery state display.
    [RTC.cpp, WifiManager.cpp]
2025-09-20 Fixed frame name (title) depending on protocol type.
    [Beacon.cpp, UiBeacon.cpp]
2025-09-22 Moved to espressif32 6.12.0. Try and fix DNS TTL.
    [WifiManager.cpp]
2025-09-28 Added cors headers. Fixed sse event fromat.
    [WifiManager.cpp]
2025-09-29 Increased decimal location precision. Fixed kvp serialization for location. Fixed frame title display. Added frame endpoint.
    [Beacon.cpp, UiBeacon.cpp, WifiManager.cpp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]
2025-10-01 Fixed buzzer hole position.
    [SarsatJRX Case Extender.FCStd]
2025-10-01 Fixed DC hole jack size.
    [SarsatJRX Case Extender.FCStd]
2025-10-01 Fixed 3.5 jack holes size (changed diameter from 7mm to 6.4mm).
    [SarsatJRX Case Extender.FCStd]
2025-10-01 Fixed back buzzer hole position (height was actually OK but moved it 0.5mm left)
    [SarsatJRX Case Extender.FCStd]
2025-10-01 New case version (small adjustements on buzzer hole, DC jack and audio jack holes)
    [Extender.stl, Top.stl]
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2025-10-02 Fixed led header display. Frame and error led stay on for 2 seconds rather than 1.
    [main.cpp]
2025-10-05 Remvoved location from Orbitography frames. Added battery percentage and sd card status to tick events. Fixed Locator display.
    [Beacon.cpp, UiBeacon.cpp, WifiManager.cpp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]
2025-10-06 Fixed frame annouce on wifi.
    [WifiManager.cpp, main.cpp]
2025-10-14 Added red frame for invalid beacons.
2025-10-14 Added reset countdown endpoint + changed reset behaviour to start countdown when paused and pause it when started.
    [Ui.cpp, WifiManager.cpp]
2025-10-15 Added 0.5 mm to top heigth.
    [SarsatJRX Case Extender.FCStd]
2025-10-15 Moved buzzer hole 0.5mm right.
    [SarsatJRX Case Extender.FCStd]
2025-10-15 Fixed insertion holes.
    [SarsatJRX Case Extender.FCStd]
2025-10-15 Updated for new JLC3DP order
    [Extender.stl, Top.stl]
2025-10-20 Moved frames app update to SSE on connect/reconnect + send missed frames on recconect. First step to settings on sse.
    [Settings.cpp, WifiManager.cpp, main.cpp]
2025-10-24 Added settings to WifiManager. Fixed DNS display.
    [WifiManager.cpp]
2025-10-26 Fixed auto-save duration. Prevent from exiting settings screen on app reconnection.
    [Settings.cpp, Ui.cpp]
2025-10-26 Fixed battery display when changing config from app.
2025-10-27 Fixed HTTP return code. Removed workstation mode. Moved buzzer sound to main loop core.
    [WifiManager.cpp, main.cpp]
2025-10-30 Fixed BL on boot.
    [Display.cpp, main.cpp]
2025-10-30 Fixed buzze level update from app.
    [WifiManager.cpp, main.cpp]
2025-10-31 Fixed 5V line capacitor value (3300uF) + footprint. Added decoupling capacitor to U2 power line. Added RV1/2 value sikl screen. Added slik screen to mark connector pins that have to be soldered. Move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
    [SarsatJRX.kicad_pcb, SarsatJRX.kicad_sch]
2025-11-04 Display code cleanup + fixed blon/off.
    [Display.cpp, Display.h]
2025-11-11 Fixed NTP date/time sync.
    [RTC.cpp]
2026-05-21 Fixed serial number calculation.
    [Beacon.cpp]
2026-06-10 - Fixed serial number calculation - Fixed HexID calculation - Added Emergency type detection and display - Added BCH1/BCH2 single bit error correction - Fixed hasBch2 calculation (only for long frame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
    [Beacon.cpp, Ui.cpp, UiBeacon.cpp]
